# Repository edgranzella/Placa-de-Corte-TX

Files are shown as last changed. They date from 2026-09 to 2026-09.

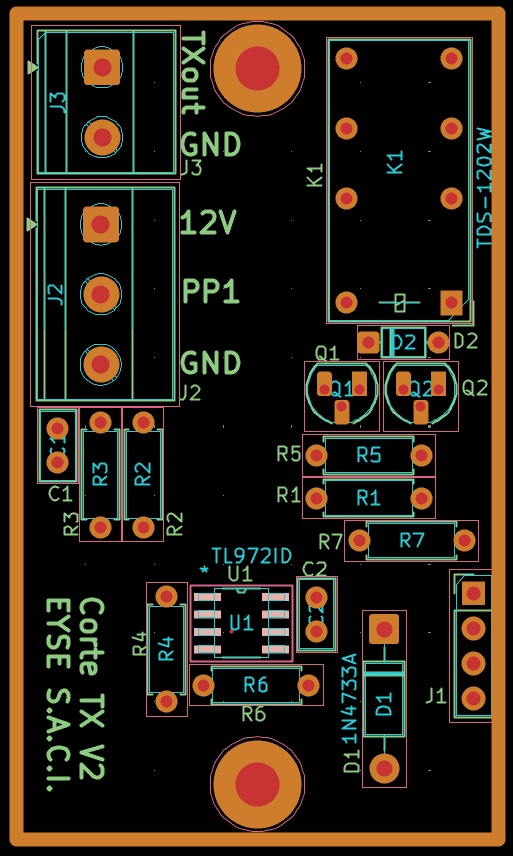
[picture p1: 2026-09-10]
Layout Placa Corte TX para Armado.jpg

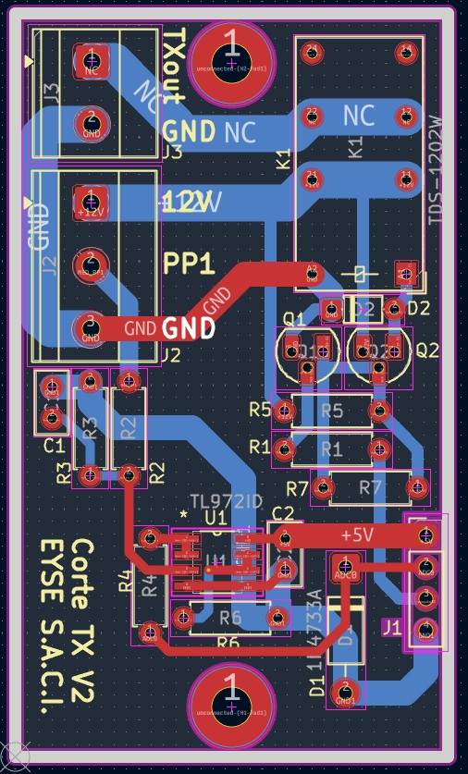
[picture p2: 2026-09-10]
Layout completo Placa Corte TX.jpg

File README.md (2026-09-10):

# Plaquetita de Corte TX - Hardware y PCB 🚀

Este repositorio contiene el diseño completo de la placa de circuito impreso (PCB) desarrollado en **KiCad** para el módulo **Plaquetita de Corte TX**. 

Este circuito está diseñado para actuar como un módulo de interrupción, conmutación o protección rápida en las líneas de transmisión (TX) o señales críticas de RF/Comunicaciones.

---

## 📌 Características del Diseño
* **Corte y Conmutación de Señal:** Etapa optimizada para la interrupción limpia de líneas de datos o transmisión sin atenuación excesiva.
* **Protección de Línea:** Incorporación de componentes de protección contra transitorios (ESD/TVS) en los terminales de entrada y salida.
* **Dimensiones Reducidas:** Diseño ultracompacto ideal para ser integrado como módulo secundario (piggyback) o en gabinetes pequeños.

---

## 🛠️ Especificaciones Técnicas de Fabricación
Configuración sugerida basada en las reglas de diseño (DRC) aplicadas en KiCad:

| Parámetro | Configuración Sugerida |
| :--- | :--- |
| **Capas (Layers)** | 2 Capas |
| **Grosor de la Placa** | 1.6 mm / 1.0 mm (si se busca menor perfil) |
| **Acabado Superficial** | HASL (with lead) o ENIG (Recomendado para señales de alta velocidad) |

---

## 👥 Desarrollado por
* **Damian Granzella** - *Ingeniería de Hardware* - [edgranzella](https://github.com)

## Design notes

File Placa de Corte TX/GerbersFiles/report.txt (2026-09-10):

Trazado a 'C:\Users\dgranzella\Documents\Placa de Corte TX\Placa de Corte TX\GerbersFiles\Placa de Corte TX-F_Cu.gbr'.
Trazado a 'C:\Users\dgranzella\Documents\Placa de Corte TX\Placa de Corte TX\GerbersFiles\Placa de Corte TX-B_Cu.gbr'.
Trazado a 'C:\Users\dgranzella\Documents\Placa de Corte TX\Placa de Corte TX\GerbersFiles\Placa de Corte TX-F_Paste.gbr'.
Trazado a 'C:\Users\dgranzella\Documents\Placa de Corte TX\Placa de Corte TX\GerbersFiles\Placa de Corte TX-F_Silkscreen.gbr'.
Trazado a 'C:\Users\dgranzella\Documents\Placa de Corte TX\Placa de Corte TX\GerbersFiles\Placa de Corte TX-F_Mask.gbr'.
Trazado a 'C:\Users\dgranzella\Documents\Placa de Corte TX\Placa de Corte TX\GerbersFiles\Placa de Corte TX-B_Mask.gbr'.
Trazado a 'C:\Users\dgranzella\Documents\Placa de Corte TX\Placa de Corte TX\GerbersFiles\Placa de Corte TX-Edge_Cuts.gbr'.
Trazado a 'C:\Users\dgranzella\Documents\Placa de Corte TX\Placa de Corte TX\GerbersFiles\Placa de Corte TX-F_Courtyard.gbr'.
Trazado a 'C:\Users\dgranzella\Documents\Placa de Corte TX\Placa de Corte TX\GerbersFiles\Placa de Corte TX-F_Fab.gbr'.
Archivo de trabajo Gerber 'C:\Users\dgranzella\Documents\Placa de Corte TX\Placa de Corte TX\GerbersFiles\Placa de Corte TX-job.gbrjob' creado.
Info: Listo.

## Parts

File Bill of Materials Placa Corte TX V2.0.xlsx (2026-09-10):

Lista de Materiales Plaquetita de Corte TX
Reference | Qty | Código | Value | Descripción
C1, C2 | 2 | 60020011 | 100nF / 50V | Condensador cerámico de inserción (THT), 100 nF, 50V.
D1 | 1 | 60040119 | 1N4733A | Diodo Zener de inserción (THT), encapsulado DO-41, tensión Zener de 5.1V, potencia de 1W.
D2 | 1 | 60041001 | 1N4148 | Diodo de conmutación rápida de inserción (THT), encapsulado DO-35, 100V, 300mA
J1 | 1 | 60002025 | Conn_01x04 | Conector macho de inserción (THT), 1 fila de 4 pines, paso estándar de 2.54 mm (0.1")
J2 | 1 | 60000002 | TBP01R1-508-03BE | Bloque de terminales de tornillo para circuito impreso (PCB) de inserción (THT), 3 pines, paso de 5.08 mm, orientación recta/salida horizontal.
J3 | 1 | 60000001 | TBP01R1-508-02BE | Bloque de terminales de tornillo para circuito impreso (PCB) de inserción (THT), 2 pines, paso de 5.08 mm, orientación recta/salida horizontal.
K1 | 1 | 60090004 | TDS-1202W | Relé electromecánico de potencia de inserción (THT), bobina de activación de 12V DC
Q1 | 1 | 60053001 | BC337 | Transistor bipolar NPN de inserción (THT), encapsulado TO-92, 45V, 800mA.
Q2 | 1 | 60053000 | BC327 | Transistor bipolar PNP de inserción (THT), encapsulado TO-92, 45V, 800mA.
R1, R5, R7 | 3 | 60012080 | 1K 1/4W | Resistencia de película de carbón o metal de inserción (THT), potencia de 1/4W (0.25W), tolerancia ±5% o ±1%.
R2 | 1 | 60012027 | 680K 1/4W | Resistencia de película de carbón o metal de inserción (THT), potencia de 1/4W (0.25W), tolerancia ±5% o ±1%.
R3 | 1 | 60012065 | 330K 1/4W | Resistencia de película de carbón o metal de inserción (THT), potencia de 1/4W (0.25W), tolerancia ±5% o ±1%.
R4 | 1 | 60012012 | 100 1/4W | Resistencia de película de carbón o metal de inserción (THT), potencia de 1/4W (0.25W), tolerancia ±5% o ±1%.
R6 | 1 | 60012071 | 1M 1/4W | Resistencia de película de carbón o metal de inserción (THT), potencia de 1/4W (0.25W), tolerancia ±5% o ±1%.
U1 | 1 | 60069210 | TL972ID | Amplificador operacional doble de bajo ruido y salida Rail-to-Rail, encapsulado de montaje superficial SOIC-8

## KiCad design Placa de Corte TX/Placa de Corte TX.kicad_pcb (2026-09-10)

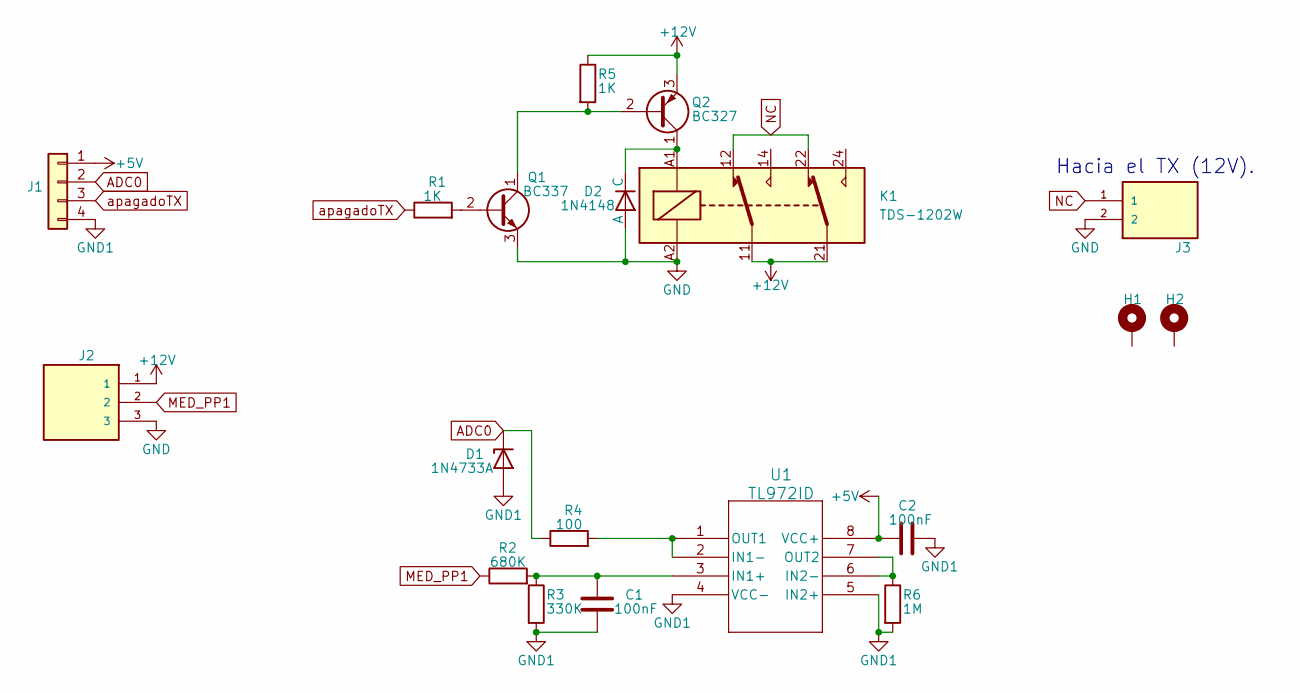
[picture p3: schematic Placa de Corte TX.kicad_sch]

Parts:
C1, C2: 100nF; C_Disc_D5.0mm_W2.5mm_P2.50mm
D1: 1N4733A; D_DO-41_SOD81_P10.16mm_Horizontal
D2: 1N4148; D_DO-35_SOD27_P5.08mm_Horizontal
H1, H2: MountingHole_Pad; MountingHole_3.2mm_M3_Pad
J1: Conn_01x04; PinHeader_1x04_P2.54mm_Vertical
J2: TBP01R1-508-03BE; TerminalBlock_Phoenix_MKDS-1,5-2-5.08_1x03_P5.08mm_Horizont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
J3: TBP01R1-508-02BE; TerminalBlock_Phoenix_MKDS-1,5-2-5.08_1x02_P5.08mm_Horizont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
K1: TDS-1202W; Relay_DPDT_Finder_30.22
Q1: BC337; TO-92_HandSolder
Q2: BC327; TO-92_HandSolder
R1, R5: 1K; R_Axial_DIN0207_L6.3mm_D2.5mm_P7.62mm_Horizontal
R2: 680K; R_Axial_DIN0207_L6.3mm_D2.5mm_P7.62mm_Horizontal
R3: 330K; R_Axial_DIN0207_L6.3mm_D2.5mm_P7.62mm_Horizontal
R4: 100; R_Axial_DIN0207_L6.3mm_D2.5mm_P7.62mm_Horizontal
R6: 1M; R_Axial_DIN0207_L6.3mm_D2.5mm_P7.62mm_Horizontal
U1: TL972ID; D8

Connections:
+5V: C2.2, J1.1, U1.8 (VCC+)
+12V: J2.1, K1.11, K1.21, Q2.3 (E), R5.1
ADC0: D1.1 (K), J1.2, R4.1
GND: D2.1 (A), J2.3, J3.2, K1.A2, Q1.3 (E)
GND1: C1.1, C2.1, D1.2 (A), J1.4, R3.2, R6.2, U1.4 (VCC-), U1.5 (IN2+)
MED_PP1: J2.2, R2.1
NC: J3.1, K1.12, K1.22
unnamed: D2.2 (C), K1.A1, Q2.1 (C)
unnamed: Q1.2 (B), R1.2
unnamed: Q1.1 (C), Q2.2 (B), R5.2
unnamed: C1.2, R2.2, R3.1, U1.3 (IN1+)
unnamed: R4.2, U1.1 (OUT1), U1.2 (IN1-)
unnamed: R6.1, U1.6 (IN2-), U1.7 (OUT2)
apagadoTX: J1.3, R1.1

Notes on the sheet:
Hacia el TX (12V).

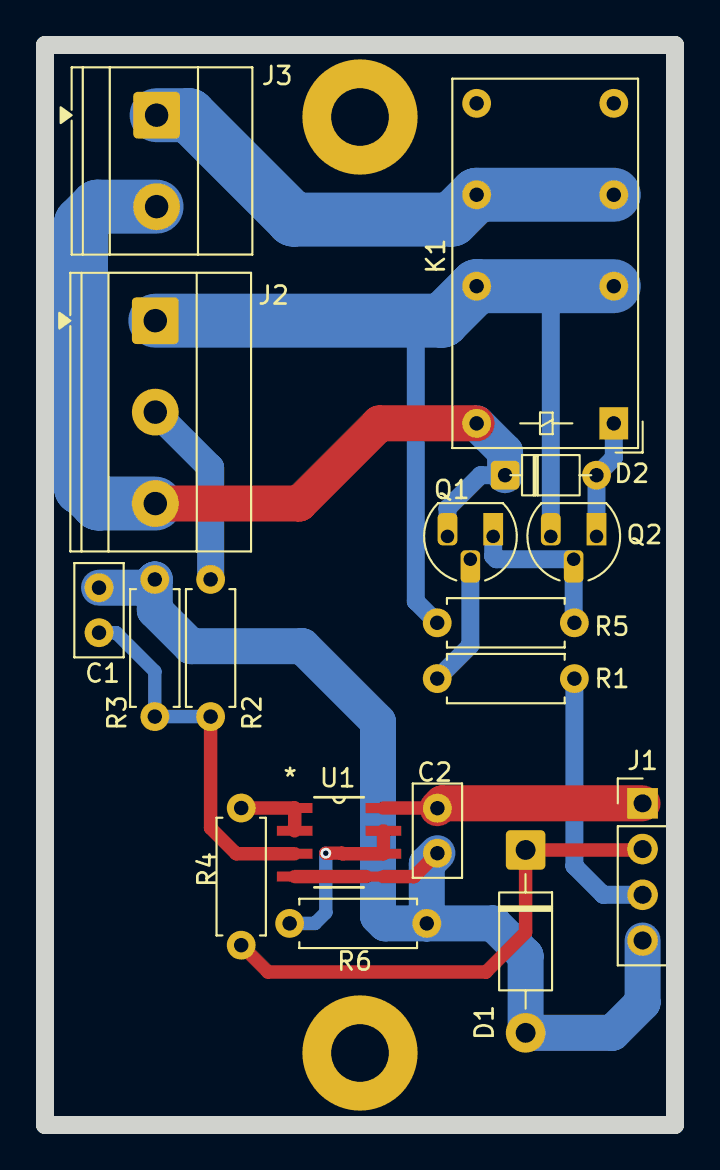
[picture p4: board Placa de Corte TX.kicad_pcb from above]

Board: 2 copper layers, 35.0 x 60.0 mm, 19 parts (0 on the bottom side), 14 nets.

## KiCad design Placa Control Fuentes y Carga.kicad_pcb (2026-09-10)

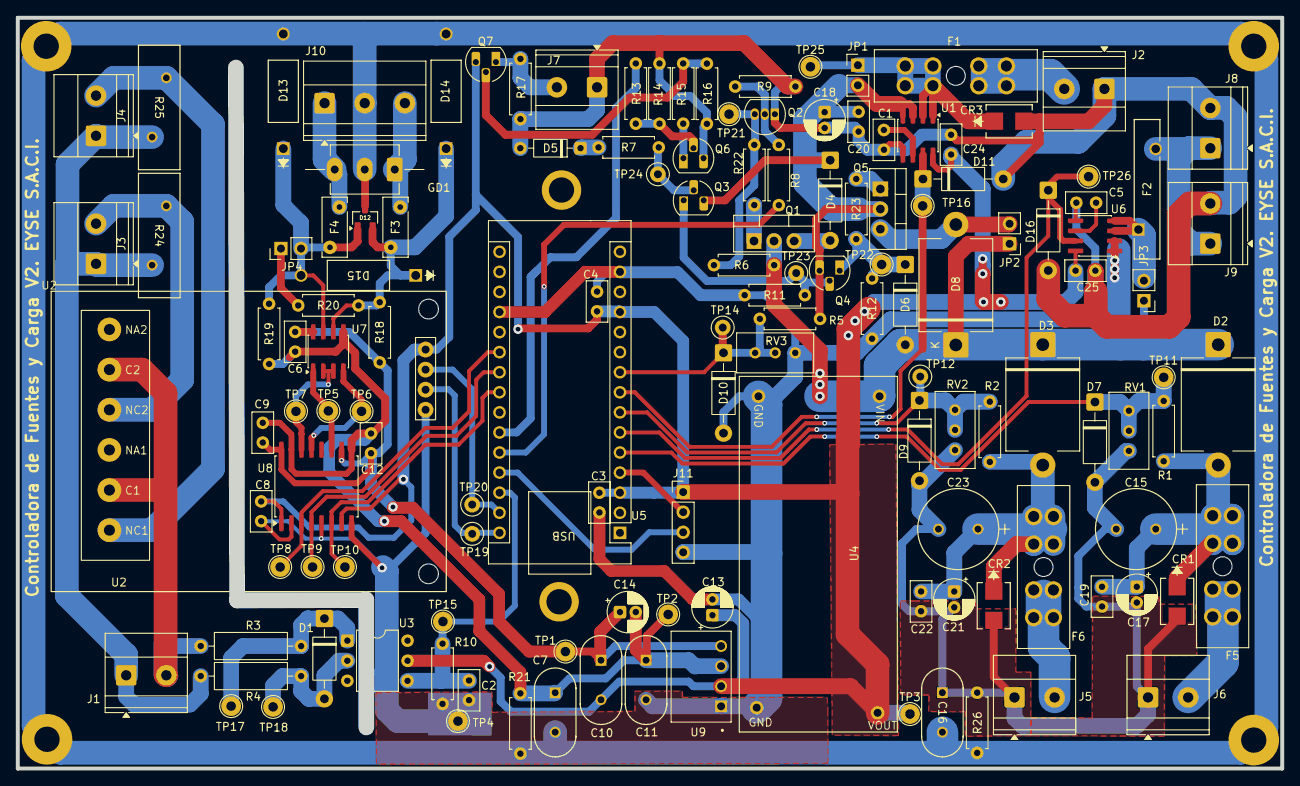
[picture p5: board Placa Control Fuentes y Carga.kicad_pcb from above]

Board: 2 copper layers, 160.0 x 95.0 mm, 142 parts (0 on the bottom side), 60 nets.

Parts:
C1, C5: 1nF; C_Disc_D5.0mm_W2.5mm_P2.50mm
C2: 22nF; C_Disc_D5.0mm_W2.5mm_P2.50mm
C3, C4, C6, C8, C9, C12, C19, C20, C22, C24, C25: 100nF; C_Disc_D5.0mm_W2.5mm_P2.50mm
C7, C10, C11, C16: F102K43Y5RP6UK5R; CAP_F_11X5P_VIS
C13, C14: 10uF; CP_Radial_D5.0mm_P2.00mm
C15, C23: 470µF/35V low-ESR; CAP_UAQ_10X20_NCH
C17, C21: 10µF/25V; CP_Radial_D5.0mm_P2.00mm
C18: 100µF/25V; CP_Radial_D5.0mm_P2.00mm
CR1, CR2: SMBJ18A; DIODE_DO214AA
CR3: SMBJ16A; DIODE_DO214AA
D1, D4, D6: 1N4007; D_DO-41_SOD81_P10.16mm_Horizontal
D2, D3, D8: P2000M; D_P600_R-6_P15.24mm_Horizontal
D5: Zener-10V; D_DO-35_SOD27_P7.62mm_Horizontal
D7, D9, D10, D11, D16: 1N4733A; D_DO-41_SOD81_P10.16mm_Horizontal
D12: SM712; SOT-23_Handsoldering
D13, D14: SA12CA; DO-204AC_SA
D15: SA6.5CA; DO-204AC_SA
F1: ETA 1610-H2-7.5A; FuseHolder_Blade_ATO_Littelfuse_FLR_178.6165
F2: Polyfuse MF-R500; FUSE_MF-R500_BRN
F3, F4: MF-R030; Fuse_Bourns_MF-RHT050
F5, F6: ETA 1610-H2-5A; FuseHolder_Blade_ATO_Littelfuse_FLR_178.6165
GD1: 2036-15-B2LF; GDT_Yageo_3RxxxxL-6
H1, H2, H3, H4, H5, H6: MountingHole_Pad; MountingHole_3.2mm_M3_Pad
J1, J2, J3, J4, J5, J6, J7, J8, J9: TBP01R1-508-02BE; TerminalBlock_Phoenix_MKDS-1,5-2-5.08_1x02_P5.08mm_Horizont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
J10: TBP01R1-508-03BE; TerminalBlock_Phoenix_MKDS-1,5-2-5.08_1x03_P5.08mm_Horizont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
J11: Conn_01x04; PinHeader_1x04_P2.54mm_Vertical
JP1, JP2, JP3, JP4: Jumper_2_Open; PinHeader_1x02_P2.54mm_Vertical
Q1: IRF9540N; TO-220-3_Vertical
Q2: 2N3904; TO-92_Inline
Q3, Q4: BC558; TO-92_HandSolder
Q5: IRF5305; TO-220-3_Vertical
Q6: BC337; TO-92_HandSolder
Q7: BC327; TO-92_HandSolder
R1, R2, R5: 150K; R_Axial_DIN0207_L6.3mm_D2.5mm_P7.62mm_Horizontal
R3, R4: 56K 0.5W; R_Axial_DIN0309_L9.0mm_D3.2mm_P12.70mm_Horizontal
R6, R9, R14, R16: 10K; R_Axial_DIN0207_L6.3mm_D2.5mm_P7.62mm_Horizontal
R7: 56K; R_Axial_DIN0207_L6.3mm_D2.5mm_P7.62mm_Horizontal
R8: 3K3; R_Axial_DIN0207_L6.3mm_D2.5mm_P7.62mm_Horizontal
R10, R11, R12: 18K; R_Axial_DIN0207_L6.3mm_D2.5mm_P7.62mm_Horizontal
R13, R15: 1K; R_Axial_DIN0207_L6.3mm_D2.5mm_P7.62mm_Horizontal
R17: 470; R_Axial_DIN0207_L6.3mm_D2.5mm_P7.62mm_Horizontal
R18, R19: 560; R_Axial_DIN0207_L6.3mm_D2.5mm_P7.62mm_Horizontal
R20: 120; R_Axial_DIN0207_L6.3mm_D2.5mm_P7.62mm_Horizontal
R21, R26: 1M; R_Axial_DIN0207_L6.3mm_D2.5mm_P7.62mm_Horizontal
R22, R23: 47; R_Axial_DIN0207_L6.3mm_D2.5mm_P7.62mm_Horizontal
R24, R25: B72214S0271K101; VARS_B72214S0271K101_TDK
RV1, RV2, RV3: 50K; Potentiometer_Bourns_3296W_Vertical
TP1, TP2, TP3, TP4, TP5, TP6, TP7, TP8, TP9, TP10, TP11, TP12, TP14, TP15, TP16, TP17, TP18, TP19, TP20, TP21, TP22, TP23, TP24, TP25, TP26: TestPoint; TestPoint_THTPad_D2.5mm_Drill1.2mm
U1, U6: ACS724LLCTR-05AB-T; SOIC-8_3.9x4.9mm_P1.27mm
U2: Relay_Module_WB-083
U3: 4N35; DIP-6_W7.62mm
U4: LM2596S_Modulo_Regulable; Modulo Step Down Regulable LM2596
U5: Arduino_Nano_ATmega328P; Arduino_Nano
U7: MAX485E; SOIC-8_3.9x4.9mm_P1.27mm
U8: MAX22445FAWE+; SOIC-16W_7.5x10.3mm_P1.27mm
U9: RI3-0505S; CONV_RI3-0505S

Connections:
+5V: C3.1, C4.1, C8.1, C10.2, C13.1, C24.2, C25.2, J11.1, Q7.3 (E), TP3.1 (1_1), U1.8 (VCC), U2.4 (VCC), U3.5, U4.4 (VOUT), U5.3 (AREF), U5.12 (5V), U6.8 (VCC), U8.1 (VDDA), U8.7 (ENA), U9.2 (+Vin)
+5V_B: C6.2, C9.2, C10.1, C12.1, C14.1, R18.1, TP1.1 (1_1), U7.8 (VCC), U8.10 (ENB), U8.16 (VDDB), U9.4 (+Vout)
+12V: D2.1 (C), D3.1 (C), D6.2 (A), D8.1 (C), JP2.1 (A), JP3.1 (A), Q1.2 (D), R6.1, U4.1 (VIN), U6.1 (IP+), U6.2 (IP+)
ADC0: J11.2, U5.4 (ADC0)
ADC1: D7.1 (K), R1.2, RV1.1, RV1.2, TP11.1 (1_1), U5.5 (ADC1)
ADC2: D16.1 (K), TP26.1 (1_1), U5.6 (ADC2), U6.7 (VIOUT)
ADC3: D9.1 (K), R2.2, RV2.1, RV2.2, TP12.1 (1_1), U5.7 (ADC3)
ADC4: D11.1 (K), TP16.1 (1_1), U1.7 (VIOUT), U5.8 (ADC4)
ADC5: D10.1 (K), R5.2, RV3.2, RV3.3, TP14.1 (1_1), U5.9 (ADC5)
DE/RE: TP8.1 (1_1), U5.21 (D3), U8.3 (IN1)
DI: TP9.1 (1_1), U5.22 (D4), U8.4 (IN2)
Earth: C7.2, C16.2, D12.3 (A), D13.2 (A), D14.2 (A), GD1.2 (GND), H1.1 (1_1), H2.1 (1_1), H3.1 (1_1), H4.1 (1_1), J10.2, R21.1, R26.1
F220_IN: C2.1, R10.1, TP15.1 (1_1), U3.4, U5.28 (D10)
F220_OUT: R13.1, U5.25 (D7)
GND: C1.1, C2.2, C3.2, C4.2, C5.1, C8.2, C11.2, C13.2, C15.2, C16.1, C17.2, C18.2, C19.2, C20.1, C21.2, C22.1, C23.2, C24.1, C25.1, CR1.2, CR2.2, CR3.2, D5.2 (A), D7.2 (A), D9.2 (A), D10.2 (A), D11.2 (A), D16.2 (A), J2.1, J5.1, J6.1, J7.1, J8.2, J9.2, J11.4, Q2.1 (E), Q6.3 (E), R9.1, R10.2, R11.2, R12.2, R14.2, R16.2, R17.2, R26.2, RV1.3, RV2.3, RV3.1, TP4.1 (1_1), U1.5 (GND), U2.1 (GND), U4.2 (GND), U4.3 (GND), U5.14 (GND), U5.19 (GND), U6.5 (GND), U8.2 (GNDA), U8.5 (IN3), U8.8 (GNDA), U9.1 (-Vin)
GND_B: C6.1, C7.1, C9.1, C11.1, C12.2, C14.2, R19.2, R21.2, TP2.1 (1_1), U7.5 (GND), U8.9 (GNDB), U8.15 (GNDB), U9.3 (-Vout)
IN1: TP19.1 (1_1), U2.2 (IN1), U5.30 (D12)
IN2: TP20.1 (1_1), U2.3 (IN2), U5.29 (D11)
unnamed: D1.2 (A), R4.2, TP18.1 (1_1), U3.2
unnamed: D1.1 (K), R3.2, TP17.1 (1_1), U3.1
unnamed: C15.1, C17.1, C19.1, CR1.1, D2.2 (A), F5.2, R1.1
unnamed: C21.1, C22.2, C23.1, CR2.1, D3.2 (A), F6.2, R2.1
unnamed: D4.2 (A), Q1.3 (S)
unnamed: C18.1, C20.2, D4.1 (K), JP1.2 (B), Q3.3 (E), Q4.3 (E), Q5.2 (D), R5.1, U1.3 (IP-), U1.4 (IP-)
unnamed: D5.1 (K), R7.2
unnamed: D6.1 (K), Q4.1 (C), R12.1, R23.1, TP22.1 (1_1)
unnamed: D8.2 (A), JP2.2 (B), Q5.3 (S)
unnamed: D12.1 (K), D13.1 (K), D15.2 (A), F4.1, JP4.2 (B), R19.1, U7.7 (B)
unnamed: D12.2 (K), D14.1 (K), D15.1 (K), F3.1, R18.2, R20.2, U7.6 (A)
unnamed: F1.1, J2.2
unnamed: F2.2, J8.1, J9.1
unnamed: F5.1, J6.2
unnamed: F6.1, J5.2
unnamed: F3.2, GD1.1 (A+), J10.3
unnamed: F4.2, GD1.3 (B-), J10.1
unnamed: J1.1, J3.1, J4.1, R4.1, R24.2, R25.2
unnamed: CR3.1, F1.2, JP1.1 (A), TP25.1 (1_1), U1.1 (IP+), U1.2 (IP+)
unnamed: F2.1, JP3.2 (B), U6.3 (IP-), U6.4 (IP-)
unnamed: JP4.1 (A), R20.1
unnamed: Q1.1 (G), R22.2
unnamed: Q2.2 (B), R8.1, R9.2
unnamed: Q2.3 (C), R6.2, R22.1, TP21.1 (1_1)
unnamed: Q3.2 (B), R7.1, TP24.1 (1_1)
unnamed: Q3.1 (C), Q4.2 (B), R11.1, TP23.1 (1_1)
unnamed: Q5.1 (G), R23.2
unnamed: Q6.2 (B), R13.2, R14.1
unnamed: Q6.1 (C), R15.1
unnamed: Q7.2 (B), R15.2, R16.1
unnamed: J7.2, Q7.1 (C), R17.1
unnamed: C1.2, U1.6 (FILTER)
unnamed: J1.2, R3.1, U2.6 (C2), U2.9 (C1)
unnamed: J4.2, R25.1, U2.10 (NC1)
unnamed: J3.2, R24.1, U2.7 (NC2)
unnamed: C5.2, U6.6 (FILTER)
unnamed: TP7.1 (1_1), U7.2 (~RE), U7.3 (DE), U8.14 (OUT1)
unnamed: TP6.1 (1_1), U7.4 (DI), U8.13 (OUT2)
unnamed: TP5.1 (1_1), U7.1 (RO), U8.11 (IN4)
PWM: R8.2, U5.26 (D8)
RO: TP10.1 (1_1), U5.23 (D5), U8.6 (OUT4)
apagadoTX: J11.3, U5.27 (D9)

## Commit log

2026-09-10 Initial commit: Estructura limpia de la plaquetita de corte TX en KiCad
    [Placa Control Fuentes y Carga.kicad_pcb, Placa de Corte TX.kicad_pcb, Placa de Corte TX.kicad_sch]
2026-09-10 Está completa la lista de materiales. El sch y el pcb ya completos y listos para que revisemos con producción.
    [Bill of Materials Placa Corte TX.xlsx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]
2026-09-10 Se agregó la R7 para limitación de la corriente de base de Q2.
    [Bill of Materials Placa Corte TX.xlsx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]
2026-09-10 Se incluye ahora la modificación de la lista de materiales.
    [Bill of Materials Placa Corte TX V2.0.xlsx]
